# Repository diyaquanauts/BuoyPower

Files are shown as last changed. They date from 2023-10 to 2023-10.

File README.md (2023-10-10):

# Buoy Power Manager
This project was created 
with KiCAD, and acts a power monitor, power timer, and voltage regulator for the 
raspberry pi.  
Boards can be assembled by JLCPCB for about $50 per set of 5. See the assembled photos below.
### Board Front 


### Board Back


# Instructional Video
Watch the video (https://youtu.be/2lVkbx-hy3E)

# Part Alternative
[Witty Pi 4](https://www.uugear.com/product/witty-pi-4/)

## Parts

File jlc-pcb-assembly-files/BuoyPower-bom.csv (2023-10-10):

Reference | Value | Footprint | Mfr 1 | Mfr 1 PN | Supplier 1 Link | Qty
BT2 | Battery_Cell | Battery:BatteryHolder_Keystone_3002_1x2032 | Keystone Electronics | 3002TR | https://www.digikey.com/en/products/detail/keystone-electronics/3002TR/306867 | 1
C2, C11 | 10uF | Capacitor_SMD:C_0805_2012Metric_Pad1.18x1.45mm_HandSolder | Samsung Electro-Mechanics | CL21A106KOCLRNC | https://www.digikey.com/en/products/detail/samsung-electro-mechanics/CL21A106KOCLRNC/3888057 | 2
C1, C3, C12, C13, C15 | 0.1uF | Capacitor_SMD:C_0805_2012Metric_Pad1.18x1.45mm_HandSolder | YAGEO | CC0805KRX7R9BB104 | https://www.digikey.com/en/products/detail/yageo/CC0805KRX7R9BB104/302874 | 5
D1, D2 | BAT20J | Diode_SMD:D_SOD-323_HandSoldering | STMicroelectronics | BAT20JFILM | https://www.digikey.com/en/products/detail/stmicroelectronics/BAT20JFILM/669137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 | 2
H2, H3 | MountingHole | MountingHole:MountingHole_3.2mm_M3_Pad_Via | NA | NA | NA | 2
J1 | Pololu-3782 | ADAFRUIT_QT_PY:Pololu-3782 | Pololu | 3782 | https://www.pololu.com/product/3782 | 1
J2 | Conn_01x05 | Connector_PinHeader_2.54mm:PinHeader_1x05_P2.54mm_Vertical | NA | NA | NA | 1
J5 | Conn_01x03 | Connector_JST:JST_XH_S3B-XH-A_1x03_P2.50mm_Horizontal | NA | NA | NA | 1
J6 | Conn_01x04 | Connector_JST:JST_SH_SM04B-SRSS-TB_1x04-1MP_P1.00mm_Horizontal | JST Sales America Inc. | SM04B-SRSS-TB | https://www.digikey.com/en/products/detail/jst-sales-america-inc/S4B-XH-A/1651041 | 1
J4, J7 | Conn_01x02_Male | Connector_JST:JST_XH_S2B-XH-A_1x02_P2.50mm_Horizontal | NA | NA | NA | 2
J8 | Conn_01x04 | Connector_JST:JST_XH_S4B-XH-A_1x04_P2.50mm_Horizontal | NA | NA | NA | 1
J9 | Conn_01x02_Male | Connector_PinHeader_2.54mm:PinHeader_1x02_P2.54mm_Vertical | NA | NA | NA | 1
J10 | Conn_02x20_Odd_Even | Connector_PinSocket_2.54mm:PinSocket_2x20_P2.54mm_Vertical | Oupiin | 2047-2X20G00S3U | https://www.digikey.com/en/products/detail/oupiin/2047-2X20G00S3U/13251053 | 1
JP2-JP4 | SolderJumper_2_Open | Jumper:SolderJumper-2_P1.3mm_Open_Pad1.0x1.5mm | NA | NA | NA | 3
JP1, JP42 | SolderJumper_2_Bridged | Jumper:SolderJumper-2_P1.3mm_Bridged_Pad1.0x1.5mm | NA | NA | NA | 2
R1 | 120k | Resistor_SMD:R_0805_2012Metric_Pad1.20x1.40mm_HandSolder | KOA Speer Electronics, Inc. | RK73H2ATTD1203F | https://www.digikey.com/en/products/detail/koa-speer-electronics-inc/RK73H2ATTD1203F/10234708 | 1
R10 | 0.15 | Resistor_SMD:R_2512_6332Metric_Pad1.40x3.35mm_HandSolder | Stackpole Electronics Inc | RMCF2512FTR150 | https://www.digikey.com/en/products/detail/stackpole-electronics-inc/RMCF2512FTR150/1716773 | 1
R11, R12 | 10 | Resistor_SMD:R_0805_2012Metric_Pad1.20x1.40mm_HandSolder | YAGEO | RC0805FR-0710RL | https://www.digikey.com/en/products/detail/yageo/RC0805FR-0710RL/727534 | 2
R13, R14 | 10k | Resistor_SMD:R_0805_2012Metric_Pad1.20x1.40mm_HandSolder | Stackpole Electronics Inc | RNCP0805FTD10K0 | https://www.digikey.com/en/products/detail/stackpole-electronics-inc/RNCP0805FTD10K0/2240262 | 2
R15 | 470k | Resistor_SMD:R_0805_2012Metric_Pad1.20x1.40mm_HandSolder | Stackpole Electronics Inc | RMCF0805JT470Kf | https://www.digikey.com/en/products/detail/stackpole-electronics-inc/RMCF0805JT470K/1757857 | 1
S1 | EG1213 | EG1213:SW_EG1213 | E-Switch | EG1213 | https://www.digikey.com/en/products/detail/e-switch/EG1213/101735?s=N4IgTCBcDaIKIHECMYkGYQF0C%2BQ | 1
U3 | INA219AxD | Package_SO:SOIC-8_3.9x4.9mm_P1.27mm | Texas Instruments | INA219BIDR | https://www.digikey.com/en/products/detail/texas-instruments/INA219BIDR/2426057 | 1
U8 | DS3231M | Package_SO:SOIC-16W_7.5x10.3mm_P1.27mm | Analog Devices Inc./Maxim Integrated | DS3231M+ | https://www.digikey.com/en/products/detail/analog-devices-inc-maxim-integrated/DS3231M/2402420 | 1
U9 | 74AHC1GU04 | Package_TO_SOT_SMD:SOT-23-5_HandSoldering | Texas Instruments | SN74AHC1GU04DBVR | https://www.digikey.com/en/products/detail/texas-instruments/SN74AHC1GU04DBVR/276739 | 1
U11 | 74AHC1G02 | Package_TO_SOT_SMD:SOT-23-5_HandSoldering | Texas Instruments | 74AHC1G02 |  | 1
Q1 | IRLML2502 |  |  | IRLML2502

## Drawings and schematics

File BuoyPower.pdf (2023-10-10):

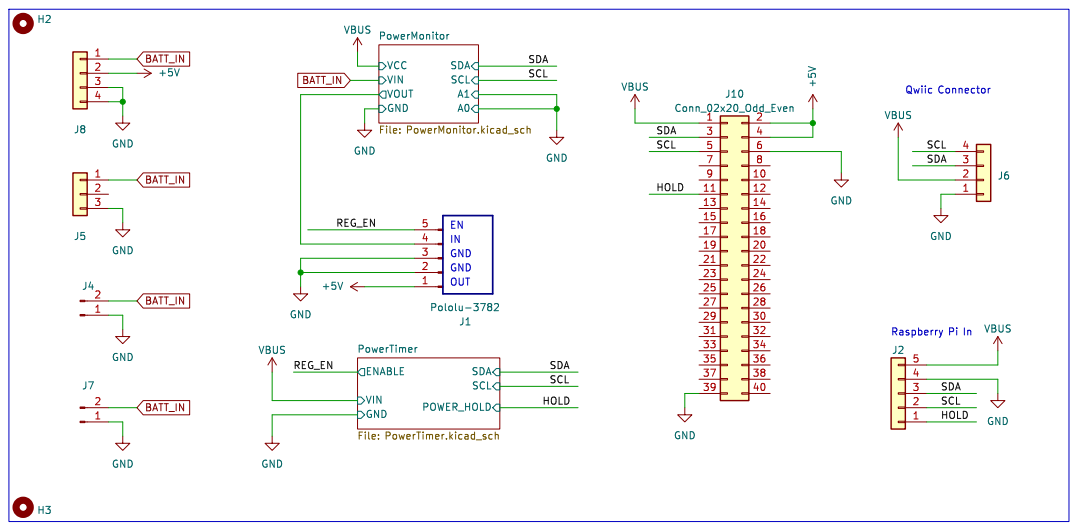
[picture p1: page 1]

PowerTimer File: PowerTimer.kicad_sch VCC
VIN GND

SCL SDA Qwiic Connector Raspberry Pi In OUT GND GND

File: BuoyPower.kicad_sch Sheet: / ENABLE
VIN

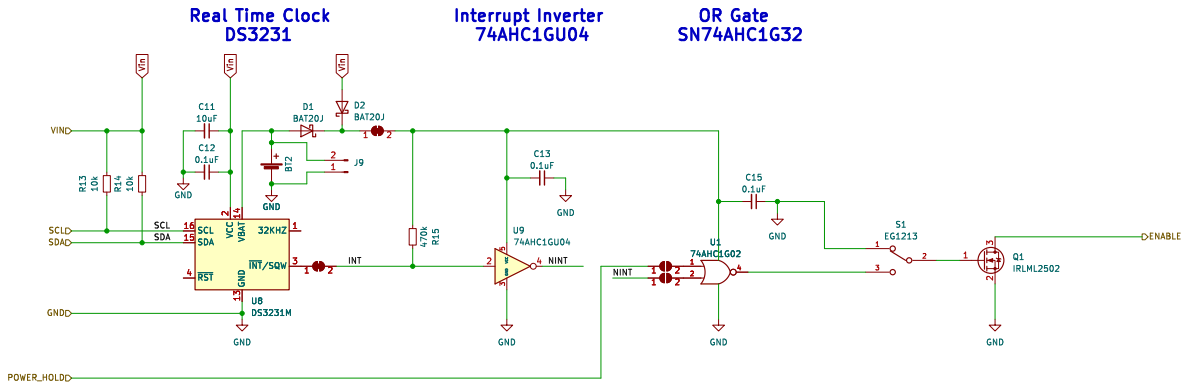
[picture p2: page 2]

2 ~{INT}/SQW 3 ~{RST} 4 GND

File: PowerTimer.kicad_sch Sheet: /PowerTimer/

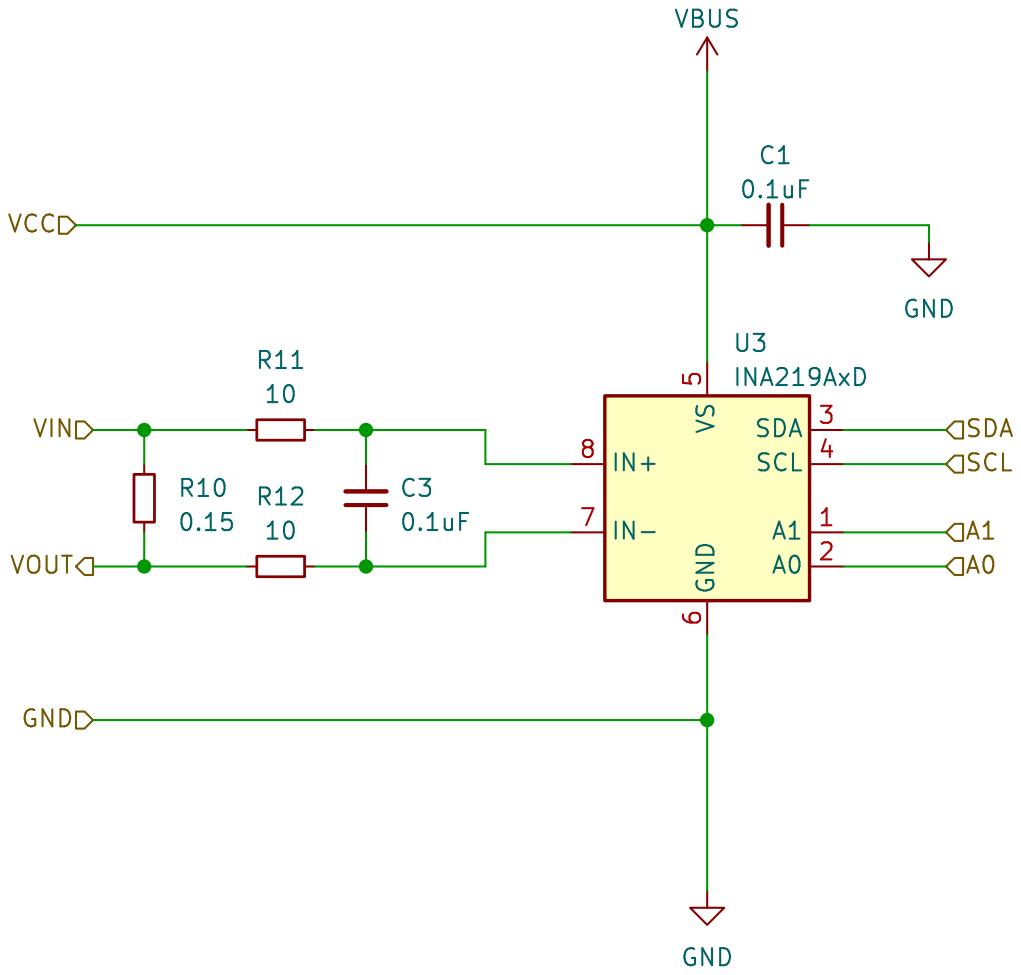
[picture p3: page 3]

File: PowerMonitor.kicad_sch Sheet: /PowerMonitor/ R10

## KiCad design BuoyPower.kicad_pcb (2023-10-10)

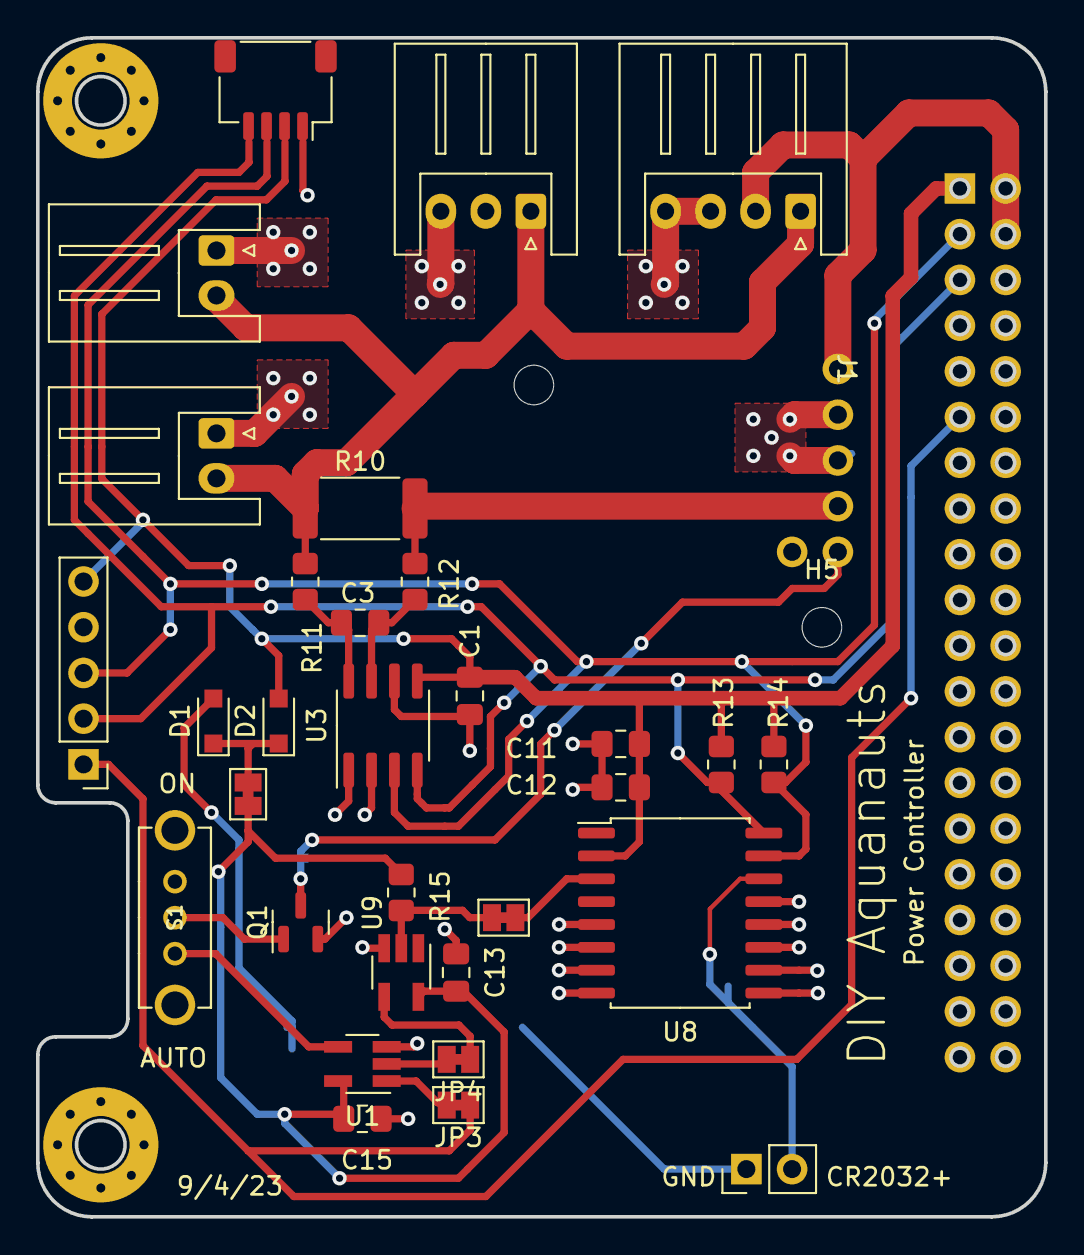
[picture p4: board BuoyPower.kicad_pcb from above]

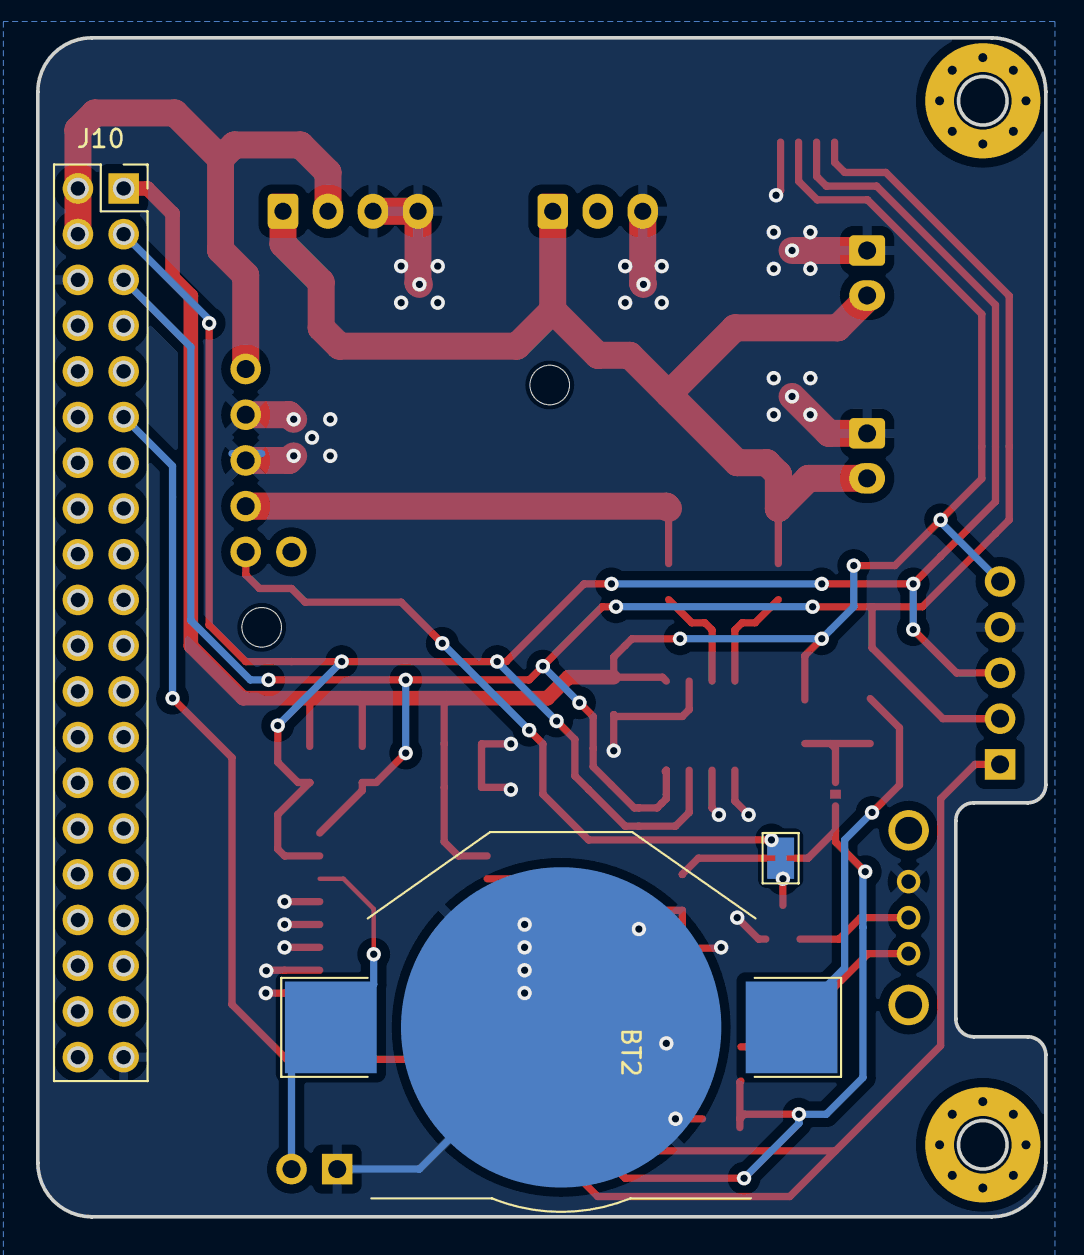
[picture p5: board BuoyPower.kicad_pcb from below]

Board: 2 copper layers, 56.0 x 65.5 mm, 39 parts (3 on the bottom side), 21 nets.

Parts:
BT2: Battery_Cell; BatteryHolder_Keystone_3002_1x2032
C1, C3, C12, C13, C15: 0.1uF; C_0805_2012Metric_Pad1.18x1.45mm_HandSolder
C11: 10uF; C_0805_2012Metric_Pad1.18x1.45mm_HandSolder
D1, D2: BAT20J; D_SOD-323_HandSoldering
H1, H5: MountingHole; MountingHole_2.2mm_M2
H2, H3: MountingHole; MountingHole_3.2mm_M3_Pad_Via
J1: Pololu-3782
J2: Conn_01x05; PinHeader_1x05_P2.54mm_Vertical
J4, J7: Conn_01x02_Male; JST_XH_S2B-XH-A_1x02_P2.50mm_Horizontal
J5: Conn_01x03; JST_XH_S3B-XH-A_1x03_P2.50mm_Horizontal
J6: Conn_01x04; JST_SH_SM04B-SRSS-TB_1x04-1MP_P1.00mm_Horizontal
J8: Conn_01x04; JST_XH_S4B-XH-A_1x04_P2.50mm_Horizontal
J9: Conn_01x02_Male; PinHeader_1x02_P2.54mm_Vertical
J10: Conn_02x20_Odd_Even; PinSocket_2x20_P2.54mm_Vertical
JP1, JP42, JP42#2: SolderJumper_2_Bridged; SolderJumper-2_P1.3mm_Bridged_Pad1.0x1.5mm
JP3, JP4: SolderJumper_2_Open; SolderJumper-2_P1.3mm_Bridged_Pad1.0x1.5mm
Q1: IRLML2502; SOT-23
R10: 0.15; R_2512_6332Metric_Pad1.40x3.35mm_HandSolder
R11, R12: 10; R_0805_2012Metric_Pad1.20x1.40mm_HandSolder
R13, R14: 10k; R_0805_2012Metric_Pad1.20x1.40mm_HandSolder
R15: 470k; R_0805_2012Metric_Pad1.20x1.40mm_HandSolder
S1: EG1213; SW_EG1213
U1: 74AHC1G02; SOT-23-5_HandSoldering
U3: INA219AxD; SOIC-8_3.9x4.9mm_P1.27mm
U8: DS3231M; SOIC-16W_7.5x10.3mm_P1.27mm
U9: 74AHC1GU04; SOT-23-5_HandSoldering

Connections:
+5V: J1.1, J8.2, J10.2, J10.4
/HOLD: J2.1, J10.11, JP3.1 (A)
/PowerMonitor/VOUT: J1.4, R10.2, R12.1
/PowerTimer/INT: JP42.2 (B), R15.2, U9.2
/PowerTimer/NINT: JP4.1 (A), U9.4
/REG_EN: J1.5, Q1.3 (D)
/SCL: J2.2, J6.4, J10.5, R13.1, U3.4 (SCL), U8.16 (SCL)
/SDA: J2.3, J6.3, J10.3, R14.1, U3.3 (SDA), U8.15 (SDA)
BATT_IN: J4.2, J5.1, J7.2, J8.1, R10.1, R11.1
GND: BT2.2 (-), C1.1, C11.2, C12.2, C13.1, C15.1, J1.2, J1.3, J2.4, J4.1, J5.3, J6.1, J7.1, J8.3, J8.4, J9.1, J10.6, J10.39, Q1.2 (S), S1.1, U1.3 (GND), U3.1 (A1), U3.2 (A0), U3.6 (GND), U8.5 (GND), U8.6 (GND), U8.7 (GND), U8.8 (GND), U8.9 (GND), U8.10 (GND), U8.11 (GND), U8.12 (GND), U8.13 (GND), U9.3 (GND)
unnamed: BT2.1 (+), D1.2 (A), J9.2, U8.14 (VBAT)
unnamed: D1.1 (K), D2.1 (K), JP1.1 (A)
unnamed: JP3.2 (B), U1.1
unnamed: JP4.2 (B), U1.2
unnamed: JP42.1 (A), U8.3 (~INT/SQW)
unnamed: Q1.1 (G), S1.2
unnamed: S1.3, U1.4
unnamed: C3.2, R11.2, U3.8 (IN+)
unnamed: C3.1, R12.2, U3.7 (IN-)
VBUS: C1.2, C11.1, C12.1, D2.2 (A), J2.5, J6.2, J10.1, R13.2, R14.2, U3.5 (VS), U8.2 (VCC)
VCC: C13.2, C15.2, JP1.2 (B), R15.1, U1.5 (VCC), U9.5 (VCC)

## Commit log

2023-09-10 Sadly, my first commit
    [BuoyPower-B_Cu.gbr, BuoyPower-B_Mask.gbr, BuoyPower-B_Paste.gbr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]
2023-09-14 Ready to order.
    [BuoyPower.kicad_pcb, BuoyPower.kicad_sch, PowerTimer.kicad_sch]
2023-09-14 Pushing to github
    [BuoyPower-B_Cu.gbr, BuoyPower-B_Mask.gbr, BuoyPower-B_Paste.gbr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]
2023-09-14 Please push
    [BuoyPower.kicad_pcb]
2023-09-14 Fix tracespace cli install
2023-09-22 Post-build updates
    [BuoyPower.csv, BuoyPower.kicad_pcb, BuoyPower.kicad_sch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]
2023-09-25 revert to single layer
    [BuoyPower-B_Cu.gbr, BuoyPower-B_Mask.gbr, BuoyPower-B_Paste.gbr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]
